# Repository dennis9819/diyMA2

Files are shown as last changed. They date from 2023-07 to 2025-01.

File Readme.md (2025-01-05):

# Modular MIDI-Controller for GrandMA2 Software
*** This project only allows you to controll the grandMA2 Software via a hardware controller. You sitll need to buy a henuine grandMA Interface to unlock the reqired amount of universes. Please also be aware, that this is just a side-project of mine and is not designed for production use. Use the real stuff for that.***

The diyMA is an open source MIDI controller, strongly mimicking the onPC command and fader wing layout. It communicates with the onPC Software via MIDI. This limits the resolution of the faders to 7-Bit (0-127). In my case this is still enough.
I've designed three modules to construct your own modular controller

## The Modules
### Module I : Fader-Module
The fader module contains:
* 5 Executor-Faders (+3 Buttons each)
* 5 Button Executor
* Controller-Header (to connect to Controller-Module)
* 2 PCBs (1x Component-PCB, 1x Panel-PCB)

### Module 3 : Controller-Module
The fader module contains:
* MIDI-In (Passed through for daisy chaining)
* MIDI-Out
* Atmega8-16P @ 16MHz
* 1 ICSP Header (programming)
* +5V/+12V Power Supply

### Module 3 : Fader-Module
The fader module contains:
* 1 Master-Fader
* 69 Buttons
* MIDI-In (Passed through for daisy chaining)
* MIDI-Out
* +5V/+12V Power Supply
* Atmega8-16P @ 16MHz
* 1 Expansion Header (e.g.: more Executors)
* 1 ICSP Header (programming)
* 2 PCBs (1x Component-PCB, 1x Panel-PCB)

## Special-Parts
* https://de.aliexpress.com/item/1005003752250659.html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
* https://de.aliexpress.com/item/1005003201365793.html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
* https://de.aliexpress.com/item/32913352658.html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

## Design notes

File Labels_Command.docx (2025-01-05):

Pause

Go -

Go +

Please

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
Shift

114

14

115

15

5

Group

Preset

Go-

Top

Thru

Fixture

Channel

Exec

Cue

Sequ

Macro

Page

Goto

Effect

View

Pause

Go+

>>>

Learn

<<<

Temp

On

Off

Select

Fix

At

If

Esc

Time

Oops

Bt Pg-

Copy

Freeze

Prev

Edit

Update

Clear

Store

Set

Next

Move

Full

Highlt

Solo

Blind

Prvw

Assign

Align

Up

Down

Ch Pg+

Ch Pg-

Fd Pg+

Fd Pg-

Bt Pg+

B.O.

Tools

Setup

Backup

Del

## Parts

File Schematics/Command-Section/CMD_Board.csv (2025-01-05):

Source: | C:\Users\DG\Desktop\diyMA\Schematics\Command-Section\CMD_Board.kicad_sch
Date: | 9/10/2023 5:42:29 PM
Tool: | Eeschema 7.0.5
Generator: | C:\Program Files\KiCad\7.0\bin\scripting\plugins/bom_csv_grouped_by_value.py
Component Count: | 175
Collated Components:
Item | Qty | Reference(s) | Value | LibPart | Footprint | Datasheet | DNP
1 | 3 | C1, C2, C5 | 100nF | Device:C_Small | Capacitor_THT:C_Rect_L7.0mm_W2.0mm_P5.00mm | ~
2 | 2 | C3, C4 | 33pF | Device:C_Small | Capacitor_THT:C_Rect_L7.0mm_W2.0mm_P5.00mm | ~
3 | 2 | C6, C7 | 100uF | Device:C_Polarized | Capacitor_THT:CP_Radial_D8.0mm_P2.50mm | ~
4 | 2 | D1, D18 | 3V6 | Device:D_Zener | Diode_THT:D_DO-35_SOD27_P10.16mm_Horizontal | ~
5 | 69 | D2, D3, D4, D5, D6, D7, D8, D9, D10, D11, D12, D13, D14, D15, D16, D17, D19, D20, D21, D22, D23, D24, D25, D26, D27, D28, D29, D30, D31, D32, D33, D34, D35, D36, D37, D38, D39, D40, D41, D42, D43, D44, D45, D46, D47, D48, D49, D50, D51, D52, D53, D54, D55, D56, D57, D58, D59, D60, D61, D62, D63, D64, D65, D66, D67, D68, D69, D70, D71 | 1N4001 | Diode:1N4001 | Diode_THT:D_DO-41_SOD81_P10.16mm_Horizontal | http://www.vishay.com/docs/88503/1n4001.pdf
6 | 12 | H1, H2, H3, H4, H5, H6, H7, H8, H9, H10, H11, H12 | MountingHole | Mechanical:MountingHole_Pad | MountingHole:MountingHole_3.2mm_M3_DIN965_Pad | ~
7 | 1 | J1 | USB_B | Connector:USB_B | Connector_USB:USB_B_Lumberg_2411_02_Horizontal | ~
8 | 1 | J2 | Conn_02x05_Odd_Even | Connector_Generic:Conn_02x05_Odd_Even | Connector_IDC:IDC-Header_2x05_P2.54mm_Vertical | ~
9 | 1 | J3 | Conn_01x04_Male | Connector:Conn_01x04_Male | Connector_JST:JST_EH_B4B-EH-A_1x04_P2.50mm_Vertical | ~
10 | 2 | J4, J5 | Conn_02x05_Odd_Even | Connector_Generic:Conn_02x05_Odd_Even | Connector_IDC:IDC-Header_2x05_P2.54mm_Latch_Vertical | ~
11 | 1 | JP1 | Jumper_2_Bridged | Jumper:Jumper_2_Bridged | Jumper:SolderJumper-2_P1.3mm_Bridged_Pad1.0x1.5mm | ~
12 | 1 | R1 | 2k2 | Device:R | Resistor_THT:R_Axial_DIN0207_L6.3mm_D2.5mm_P7.62mm_Horizontal | ~
13 | 2 | R2, R3 | 68 | Device:R | Resistor_THT:R_Axial_DIN0207_L6.3mm_D2.5mm_P7.62mm_Horizontal | ~
14 | 1 | R4 | 10k | Device:R | Resistor_THT:R_Axial_DIN0204_L3.6mm_D1.6mm_P2.54mm_Vertical | ~
15 | 1 | RN1 | R_Network08 | Device:R_Network08 | Resistor_THT:R_Array_SIP9 | http://www.vishay.com/docs/31509/csc.pdf
16 | 1 | RV1 | 10K LIN | Device:R_Potentiometer | w_conn_av:RS60N12-LIN10K | ~
17 | 69 | SW1, SW2, SW3, SW4, SW5, SW6, SW7, SW8, SW9, SW10, SW11, SW12, SW13, SW14, SW15, SW16, SW17, SW18, SW19, SW20, SW21, SW22, SW23, SW24, SW25, SW26, SW27, SW28, SW29, SW30, SW31, SW32, SW33, SW34, SW35, SW36, SW37, SW38, SW39, SW40, SW41, SW42, SW43, SW44, SW45, SW46, SW47, SW48, SW49, SW50, SW51, SW52, SW53, SW54, SW55, SW56, SW57, SW58, SW59, SW60, SW61, SW62, SW63, SW64, SW65, SW66, SW67, SW68, SW69 | Switch_SW_DPST | Z8C rev3-cache:Switch_SW_DPST | cherrymx:SW_Cherry_MX_PCB_1.00u
18 | 1 | U1 | 74HC595 | 74xx:74HC595 | Package_DIP:DIP-16_W7.62mm_Socket_LongPads | http://www.ti.com/lit/ds/symlink/sn74hc595.pdf
19 | 1 | U2 | L7805 | Regulator_Linear:L7805 | Package_TO_SOT_THT:TO-220-3_Horizontal_TabDown | http://www.st.com/content/ccc/resource/technical/document/datasheet/41/4f/b3/b0/12/d4/47/88/CD00000444.pdf/files/CD00000444.pdf/jcr:content/translations/en.CD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
20 | 1 | U3 | ATmega8-16P | MCU_Microchip_ATmega:ATmega8-16P | Package_DIP:DIP-28_W7.62mm_LongPads | http://ww1.microchip.com/downloads/en/DeviceDoc/atmel-2486-8-bit-avr-microcontroller-atmega8_l_datasheet.pdf
21 | 1 | Y1 | 16MHz | Device:Crystal | Crystal:Crystal_HC18-U_Vertical | ~

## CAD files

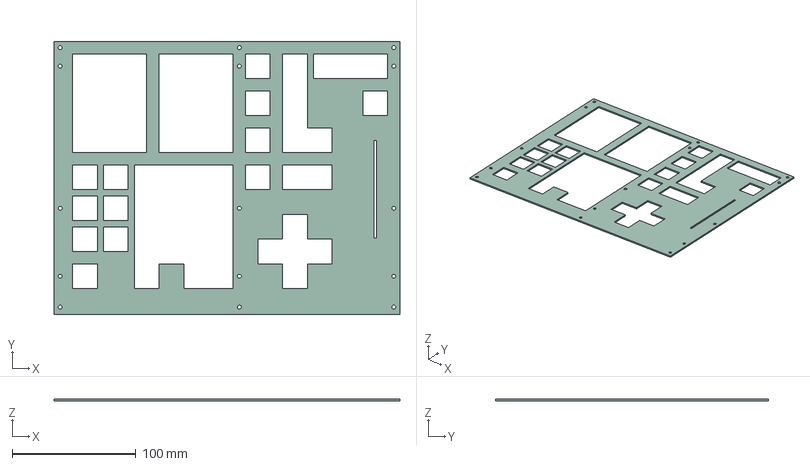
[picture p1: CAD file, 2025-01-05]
Schematics/Command-Section/CMD_Board_cover.step
280.0 x 221.0 x 1.58 mm

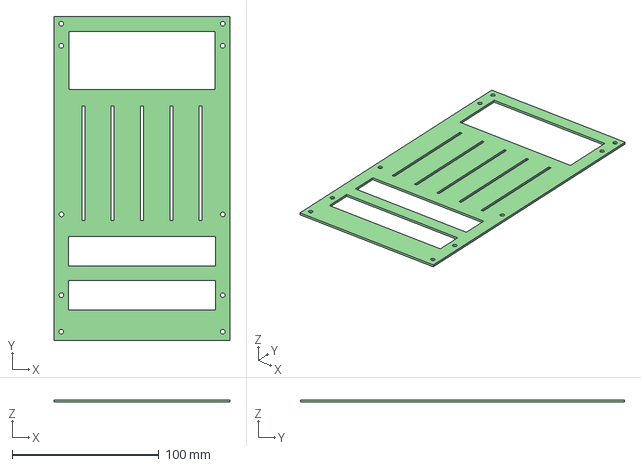
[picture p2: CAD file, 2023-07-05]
Schematics/Fader-Wing V1/Fader_Board_panel.step
120.0 x 221.0 x 1.60 mm

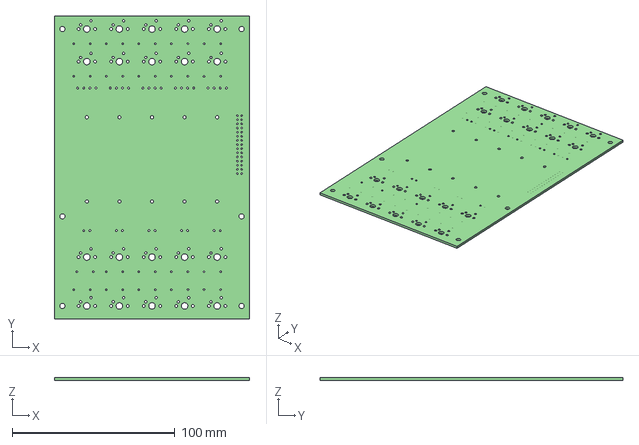
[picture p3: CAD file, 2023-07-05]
Schematics/Fader-Wing V1/Fader_Board.step
120.0 x 186.0 x 1.60 mm

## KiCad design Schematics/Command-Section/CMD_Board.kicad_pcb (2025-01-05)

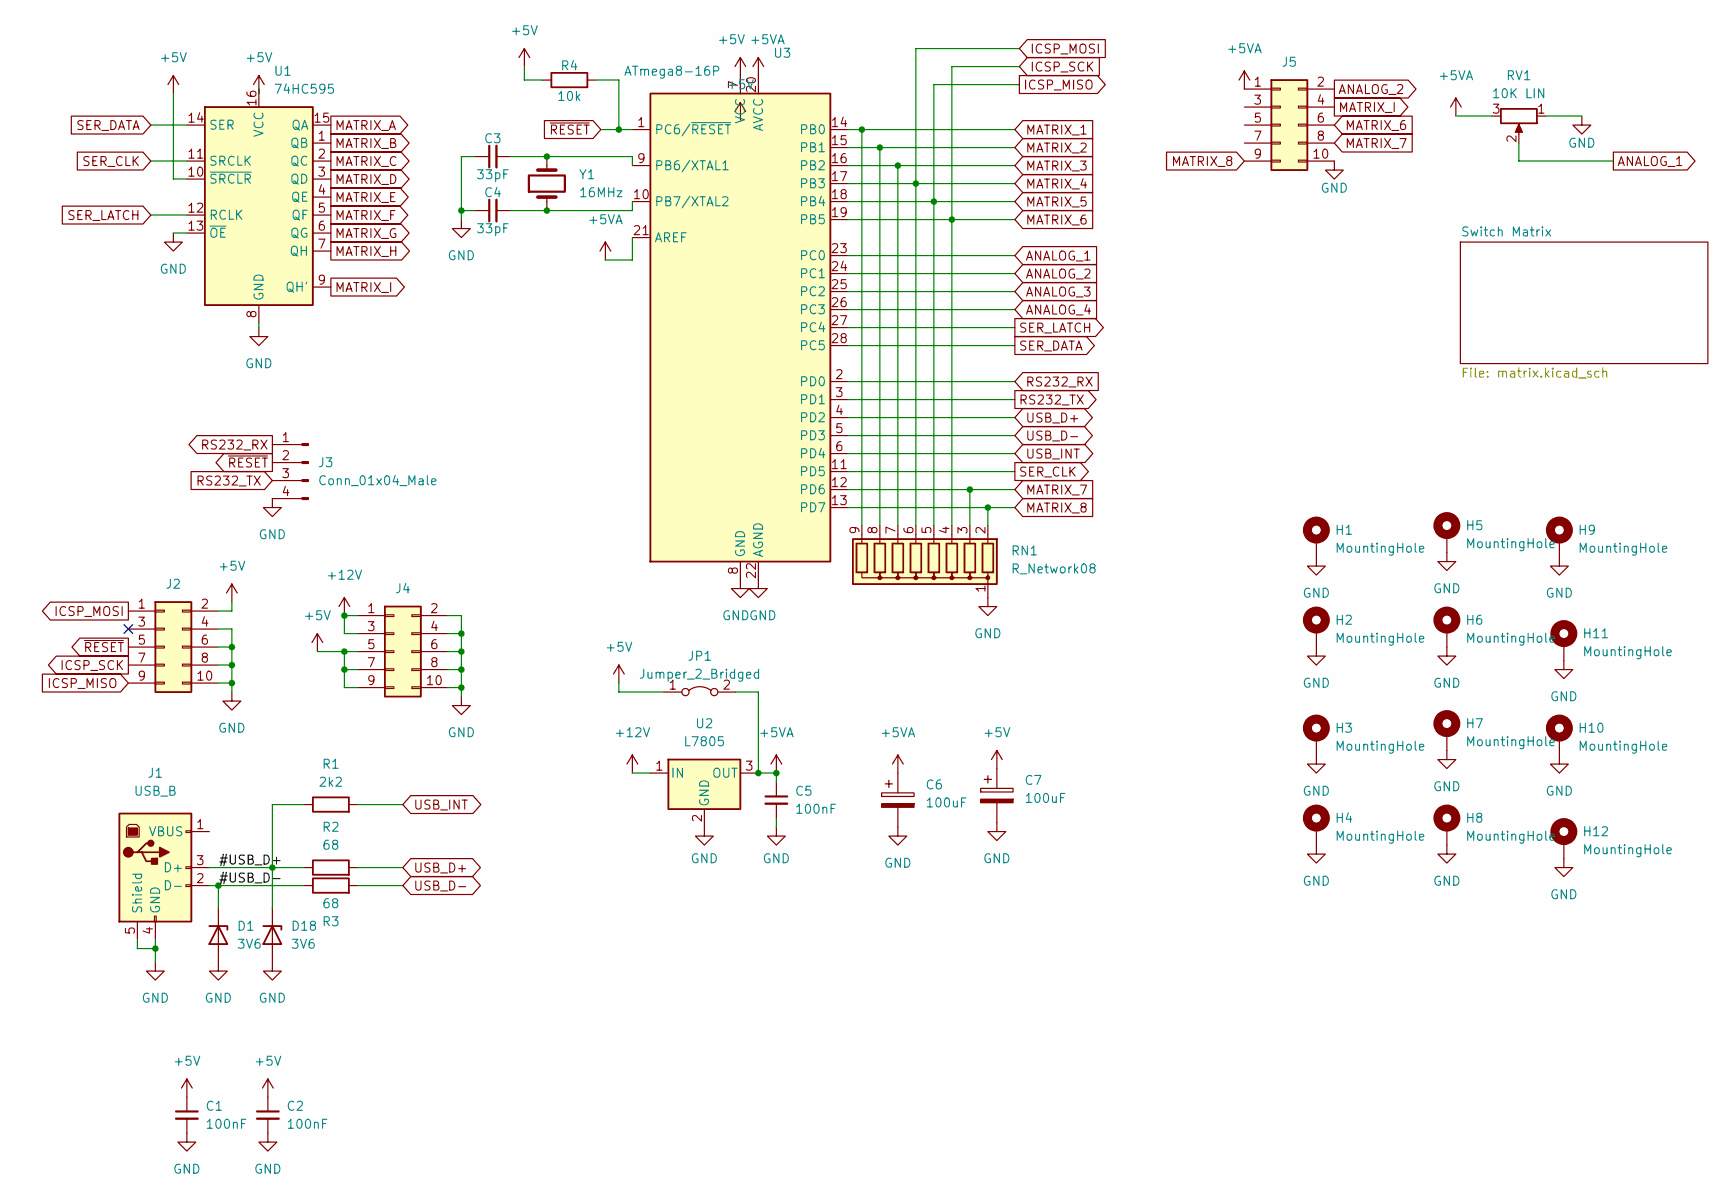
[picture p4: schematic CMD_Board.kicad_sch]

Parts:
C1, C2, C5: 100nF; C_Rect_L7.0mm_W2.0mm_P5.00mm
C3, C4: 33pF; C_Rect_L7.0mm_W2.0mm_P5.00mm
C6, C7: 100uF; CP_Radial_D8.0mm_P2.50mm
D1, D18: 3V6; D_DO-35_SOD27_P10.16mm_Horizontal
H1, H2, H3, H4, H5, H6, H7, H8, H9, H10, H11, H12: MountingHole; MountingHole_3.2mm_M3_DIN965_Pad
J1: USB_B; USB_B_Lumberg_2411_02_Horizontal
J2: Conn_02x05_Odd_Even; IDC-Header_2x05_P2.54mm_Vertical
J3: Conn_01x04_Male; JST_EH_B4B-EH-A_1x04_P2.50mm_Vertical
J4, J5: Conn_02x05_Odd_Even; IDC-Header_2x05_P2.54mm_Latch_Vertical
JP1: Jumper_2_Bridged; SolderJumper-2_P1.3mm_Bridged_Pad1.0x1.5mm
R1: 2k2; R_Axial_DIN0207_L6.3mm_D2.5mm_P7.62mm_Horizontal
R2, R3: 68; R_Axial_DIN0207_L6.3mm_D2.5mm_P7.62mm_Horizontal
R4: 10k; R_Axial_DIN0204_L3.6mm_D1.6mm_P2.54mm_Vertical
RN1: R_Network08; R_Array_SIP9
RV1: 10K LIN; RS60N12-LIN10K
U1: 74HC595; DIP-16_W7.62mm_Socket_LongPads
U2: L7805; TO-220-3_Horizontal_TabDown
U3: ATmega8-16P; DIP-28_W7.62mm_LongPads
Y1: 16MHz; Crystal_HC18-U_Vertical

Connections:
+5V: C1.1, C2.1, C7.1, J2.2, J4.5, J4.7, J4.9, JP1.1 (A), R4.1, U1.10 (~SRCLR), U1.16 (VCC), U3.7 (VCC)
+5VA: C5.1, C6.1, J5.1, JP1.2 (B), RV1.3, U2.3 (OUT), U3.20 (AVCC), U3.21 (AREF)
+12V: J4.1, J4.3, U2.1 (IN)
/#USB_D+: D18.1 (K), J1.3 (D+), R1.1, R2.1
/#USB_D-: D1.1 (K), J1.2 (D-), R3.1
ANALOG_1: RV1.2, U3.23 (PC0)
ANALOG_2: J5.2, U3.24 (PC1)
ANALOG_3: U3.25 (PC2)
ANALOG_4: U3.26 (PC3)
GND: C1.2, C2.2, C3.1, C4.1, C5.2, C6.2, C7.2, D1.2 (A), D18.2 (A), H1.1, H2.1, H3.1, H4.1, H5.1, H6.1, H7.1, H8.1, H9.1, H10.1, H11.1, H12.1, J1.4 (GND), J1.5 (Shield), J2.4, J2.6, J2.8, J2.10, J3.4, J4.2, J4.4, J4.6, J4.8, J4.10, J5.10, RN1.1 (common), RV1.1, U1.8 (GND), U1.13 (~OE), U2.2 (GND), U3.8 (GND), U3.22 (AGND); also elsewhere on the board
ICSP_MISO: J2.9, RN1.5 (R4), U3.18 (PB4); also elsewhere on the board
ICSP_MOSI: J2.1, RN1.6 (R5), U3.17 (PB3); also elsewhere on the board
ICSP_SCK: J2.7, J5.6, RN1.4 (R3), U3.19 (PB5); also elsewhere on the board
MATRIX_1: RN1.9 (R8), U3.14 (PB0); also elsewhere on the board
MATRIX_2: RN1.8 (R7), U3.15 (PB1); also elsewhere on the board
MATRIX_3: RN1.7 (R6), U3.16 (PB2); also elsewhere on the board
MATRIX_7: J5.8, RN1.3 (R2), U3.12 (PD6); also elsewhere on the board
MATRIX_8: J5.9, RN1.2 (R1), U3.13 (PD7); also elsewhere on the board
MATRIX_A: U1.15 (QA); also elsewhere on the board
MATRIX_B: U1.1 (QB); also elsewhere on the board
MATRIX_C: U1.2 (QC); also elsewhere on the board
MATRIX_D: U1.3 (QD); also elsewhere on the board
MATRIX_E: U1.4 (QE); also elsewhere on the board
MATRIX_F: U1.5 (QF); also elsewhere on the board
MATRIX_G: U1.6 (QG); also elsewhere on the board
MATRIX_H: U1.7 (QH); also elsewhere on the board
MATRIX_I: J5.4, U1.9 (QH'); also elsewhere on the board
unnamed: C3.2, U3.9 (PB6/XTAL1), Y1.2
unnamed: C4.2, U3.10 (PB7/XTAL2), Y1.1
RS232_RX: J3.1, U3.2 (PD0)
RS232_TX: J3.3, U3.3 (PD1)
SER_CLK: U1.11 (SRCLK), U3.11 (PD5)
SER_DATA: U1.14 (SER), U3.28 (PC5)
SER_LATCH: U1.12 (RCLK), U3.27 (PC4)
USB_D+: R2.2, U3.4 (PD2)
USB_D-: R3.2, U3.5 (PD3)
USB_INT: R1.2, U3.6 (PD4)
~RESET: J2.5, J3.2, R4.2, U3.1 (PC6/~RESET)

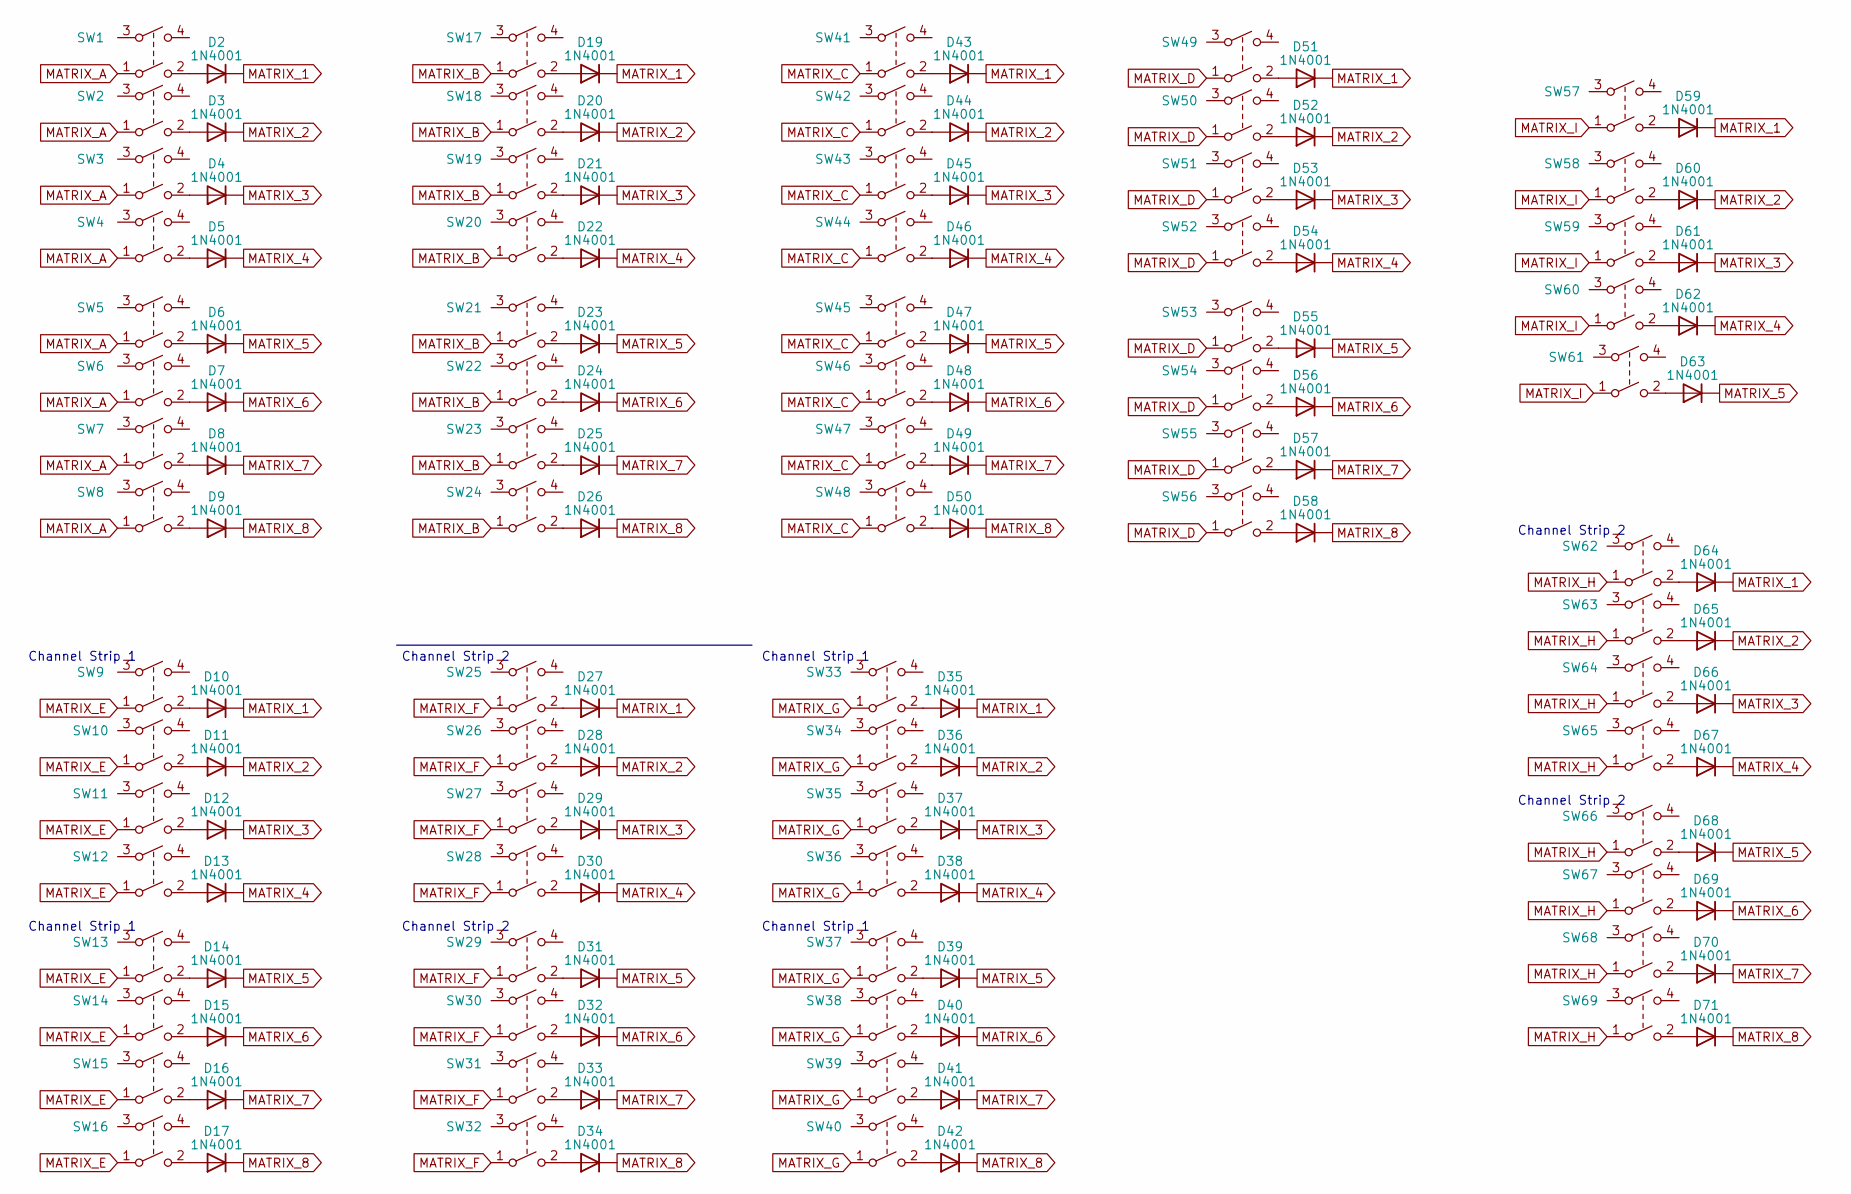
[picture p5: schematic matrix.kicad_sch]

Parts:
D2, D3, D4, D5, D6, D7, D8, D9, D10, D11, D12, D13, D14, D15, D16, D17, D19, D20, D21, D22, D23, D24, D25, D26, D27, D28, D29, D30, D31, D32, D33, D34, D35, D36, D37, D38, D39, D40, D41, D42, D43, D44, D45, D46, D47, D48, D49, D50, D51, D52, D53, D54, D55, D56, D57, D58, D59, D60, D61, D62, D63, D64, D65, D66, D67, D68, D69, D70, D71: 1N4001; D_DO-41_SOD81_P10.16mm_Horizontal
SW1, SW2, SW3, SW4, SW5, SW6, SW7, SW8, SW9, SW10, SW11, SW12, SW13, SW14, SW15, SW16, SW17, SW18, SW19, SW20, SW21, SW22, SW23, SW24, SW25, SW26, SW27, SW28, SW29, SW30, SW31, SW32, SW33, SW34, SW35, SW36, SW37, SW38, SW39, SW40, SW41, SW42, SW43, SW44, SW45, SW46, SW47, SW48, SW49, SW50, SW51, SW52, SW53, SW54, SW55, SW56, SW57, SW58, SW59, SW60, SW61, SW62, SW63, SW64, SW65, SW66, SW67, SW68, SW69: Switch_SW_DPST; SW_Cherry_MX_PCB_1.00u

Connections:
ICSP_MISO: D6.1 (K), D14.1 (K), D23.1 (K), D31.1 (K), D39.1 (K), D47.1 (K), D55.1 (K), D63.1 (K), D68.1 (K); also elsewhere on the board
ICSP_MOSI: D5.1 (K), D13.1 (K), D22.1 (K), D30.1 (K), D38.1 (K), D46.1 (K), D54.1 (K), D62.1 (K), D67.1 (K); also elsewhere on the board
ICSP_SCK: D7.1 (K), D15.1 (K), D24.1 (K), D32.1 (K), D40.1 (K), D48.1 (K), D56.1 (K), D69.1 (K); also elsewhere on the board
MATRIX_1: D2.1 (K), D10.1 (K), D19.1 (K), D27.1 (K), D35.1 (K), D43.1 (K), D51.1 (K), D59.1 (K), D64.1 (K); also elsewhere on the board
MATRIX_2: D3.1 (K), D11.1 (K), D20.1 (K), D28.1 (K), D36.1 (K), D44.1 (K), D52.1 (K), D60.1 (K), D65.1 (K); also elsewhere on the board
MATRIX_3: D4.1 (K), D12.1 (K), D21.1 (K), D29.1 (K), D37.1 (K), D45.1 (K), D53.1 (K), D61.1 (K), D66.1 (K); also elsewhere on the board
MATRIX_7: D8.1 (K), D16.1 (K), D25.1 (K), D33.1 (K), D41.1 (K), D49.1 (K), D57.1 (K), D70.1 (K); also elsewhere on the board
MATRIX_8: D9.1 (K), D17.1 (K), D26.1 (K), D34.1 (K), D42.1 (K), D50.1 (K), D58.1 (K), D71.1 (K); also elsewhere on the board
MATRIX_A: SW1.1, SW2.1, SW3.1, SW4.1, SW5.1, SW6.1, SW7.1, SW8.1; also elsewhere on the board
MATRIX_B: SW17.1, SW18.1, SW19.1, SW20.1, SW21.1, SW22.1, SW23.1, SW24.1; also elsewhere on the board
MATRIX_C: SW41.1, SW42.1, SW43.1, SW44.1, SW45.1, SW46.1, SW47.1, SW48.1; also elsewhere on the board
MATRIX_D: SW49.1, SW50.1, SW51.1, SW52.1, SW53.1, SW54.1, SW55.1, SW56.1; also elsewhere on the board
MATRIX_E: SW9.1, SW10.1, SW11.1, SW12.1, SW13.1, SW14.1, SW15.1, SW16.1; also elsewhere on the board
MATRIX_F: SW25.1, SW26.1, SW27.1, SW28.1, SW29.1, SW30.1, SW31.1, SW32.1; also elsewhere on the board
MATRIX_G: SW33.1, SW34.1, SW35.1, SW36.1, SW37.1, SW38.1, SW39.1, SW40.1; also elsewhere on the board
MATRIX_H: SW62.1, SW63.1, SW64.1, SW65.1, SW66.1, SW67.1, SW68.1, SW69.1; also elsewhere on the board
MATRIX_I: SW57.1, SW58.1, SW59.1, SW60.1, SW61.1; also elsewhere on the board
unnamed: D2.2 (A), SW1.2
unnamed: D3.2 (A), SW2.2
unnamed: D4.2 (A), SW3.2
unnamed: D5.2 (A), SW4.2
unnamed: D6.2 (A), SW5.2
unnamed: D7.2 (A), SW6.2
unnamed: D8.2 (A), SW7.2
unnamed: D9.2 (A), SW8.2
unnamed: D10.2 (A), SW9.2
unnamed: D11.2 (A), SW10.2
unnamed: D12.2 (A), SW11.2
unnamed: D13.2 (A), SW12.2
unnamed: D14.2 (A), SW13.2
unnamed: D15.2 (A), SW14.2
unnamed: D16.2 (A), SW15.2
unnamed: D17.2 (A), SW16.2
unnamed: D19.2 (A), SW17.2
unnamed: D20.2 (A), SW18.2
unnamed: D21.2 (A), SW19.2
unnamed: D22.2 (A), SW20.2
unnamed: D23.2 (A), SW21.2
unnamed: D24.2 (A), SW22.2
unnamed: D25.2 (A), SW23.2
unnamed: D26.2 (A), SW24.2
unnamed: D27.2 (A), SW25.2
unnamed: D28.2 (A), SW26.2
unnamed: D29.2 (A), SW27.2
unnamed: D30.2 (A), SW28.2
unnamed: D31.2 (A), SW29.2
unnamed: D32.2 (A), SW30.2
unnamed: D33.2 (A), SW31.2
unnamed: D34.2 (A), SW32.2
unnamed: D35.2 (A), SW33.2
unnamed: D36.2 (A), SW34.2
unnamed: D37.2 (A), SW35.2
unnamed: D38.2 (A), SW36.2
unnamed: D39.2 (A), SW37.2
unnamed: D40.2 (A), SW38.2
unnamed: D41.2 (A), SW39.2
unnamed: D42.2 (A), SW40.2
unnamed: D43.2 (A), SW41.2
unnamed: D44.2 (A), SW42.2
unnamed: D45.2 (A), SW43.2
unnamed: D46.2 (A), SW44.2
unnamed: D47.2 (A), SW45.2
unnamed: D48.2 (A), SW46.2
unnamed: D49.2 (A), SW47.2
unnamed: D50.2 (A), SW48.2
unnamed: D51.2 (A), SW49.2
unnamed: D52.2 (A), SW50.2
unnamed: D53.2 (A), SW51.2
unnamed: D54.2 (A), SW52.2
unnamed: D55.2 (A), SW53.2
unnamed: D56.2 (A), SW54.2
unnamed: D57.2 (A), SW55.2
unnamed: D58.2 (A), SW56.2
unnamed: D59.2 (A), SW57.2
unnamed: D60.2 (A), SW58.2
unnamed: D61.2 (A), SW59.2
unnamed: D62.2 (A), SW60.2
unnamed: D63.2 (A), SW61.2
unnamed: D64.2 (A), SW62.2
unnamed: D65.2 (A), SW63.2
unnamed: D66.2 (A), SW64.2
unnamed: D67.2 (A), SW65.2
unnamed: D68.2 (A), SW66.2
unnamed: D69.2 (A), SW67.2
unnamed: D70.2 (A), SW68.2
unnamed: D71.2 (A), SW69.2

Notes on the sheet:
Channel Strip 2
Channel Strip 1

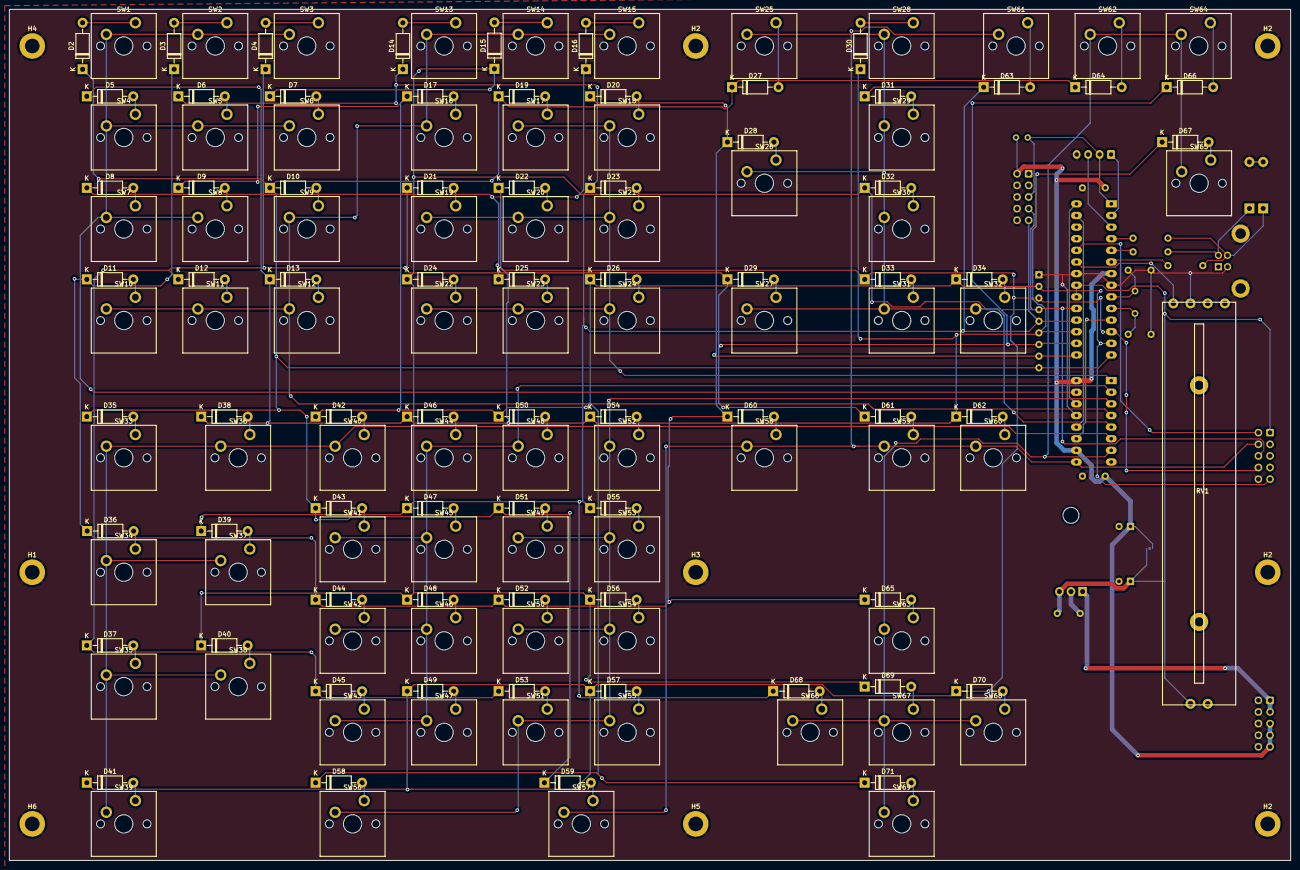
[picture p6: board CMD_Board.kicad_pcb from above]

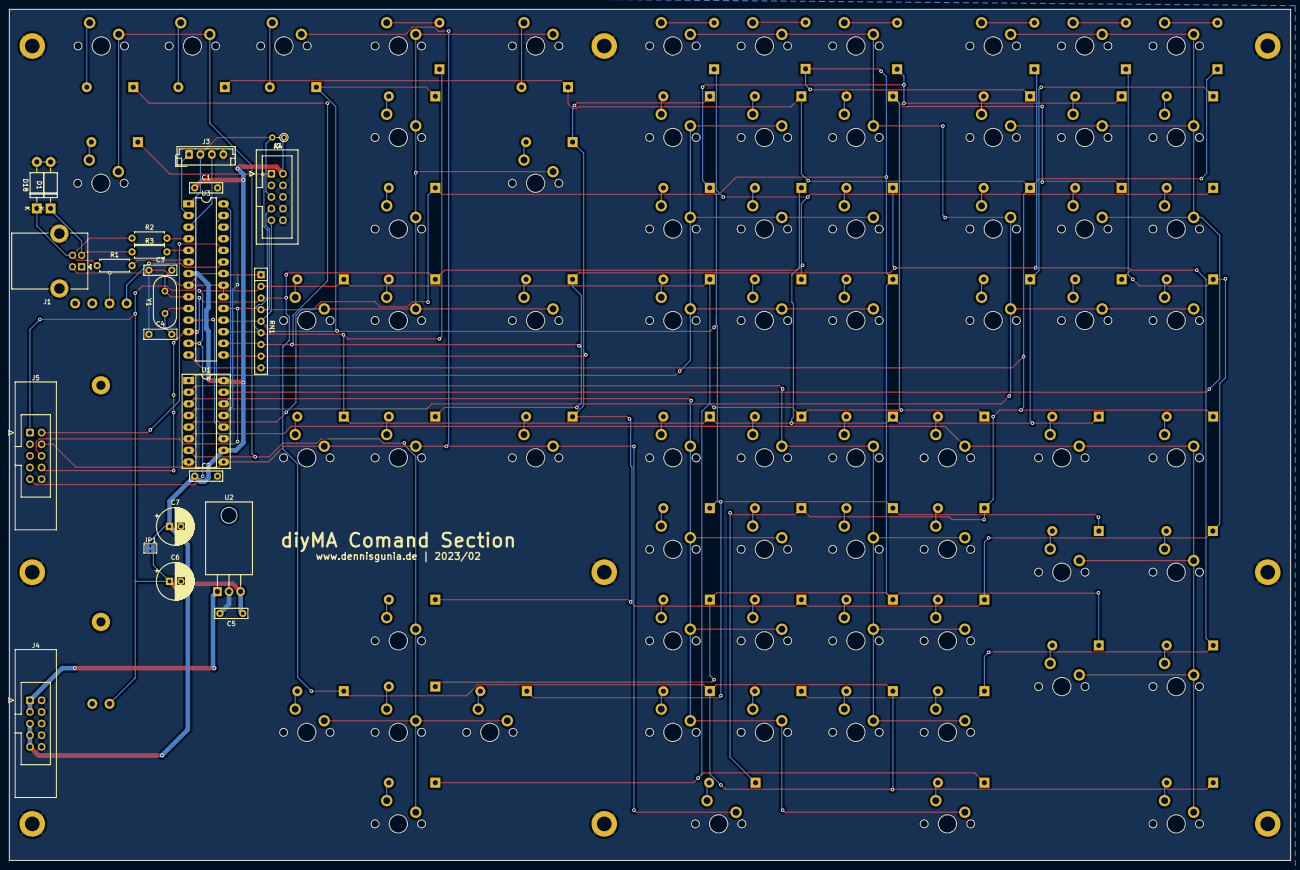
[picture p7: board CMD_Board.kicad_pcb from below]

Board: 2 copper layers, 280.0 x 186.0 mm, 172 parts (24 on the bottom side), 105 nets.

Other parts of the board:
H2#2, H2#3, H2#4: MountingHole; MountingHole_3.2mm_M3_DIN965_Pad

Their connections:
GND: H2#2.1, H2#3.1, H2#4.1; also elsewhere on the board

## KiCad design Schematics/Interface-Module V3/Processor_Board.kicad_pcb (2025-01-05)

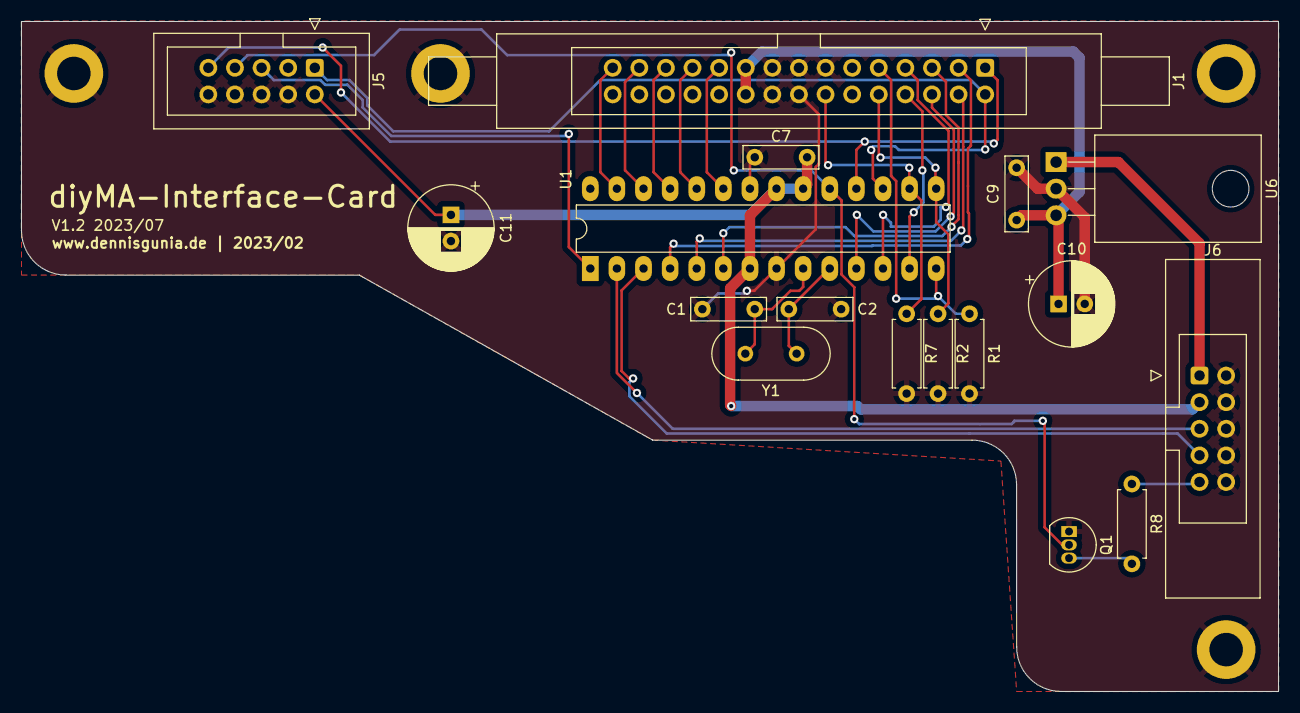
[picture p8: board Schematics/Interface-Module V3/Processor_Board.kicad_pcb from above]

Board: 2 copper layers, 120.0 x 64.0 mm, 21 parts (0 on the bottom side), 28 nets.

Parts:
C1, C2: 33pF; C_Rect_L7.0mm_W2.0mm_P5.00mm
C7, C9: 100nF; C_Rect_L7.0mm_W2.0mm_P5.00mm
C10, C11: 100uF; CP_Radial_D8.0mm_P2.50mm
H4, H6, H6#2, H8: MountingHole; MountingHole_3.2mm_M3_DIN965_Pad
J1: Conn_02x16_Odd_Even; IDC-Header_2x15_P2.54mm_Latch6.5mm_Vertical
J5: Conn_02x05_Odd_Even; IDC-Header_2x05_P2.54mm_Vertical
J6: Conn_02x05_Odd_Even; IDC-Header_2x05_P2.54mm_Latch_Vertical
Q1: 2N3904; TO-92_Inline
R1, R2, R7: 10k; R_Axial_DIN0207_L6.3mm_D2.5mm_P7.62mm_Horizontal
R8: 100; R_Axial_DIN0207_L6.3mm_D2.5mm_P7.62mm_Horizontal
U1: ATmega8-16P; DIP-28_W7.62mm_LongPads
U6: L7805; TO-220-3_Horizontal_TabDown
Y1: 16MHz; Crystal_HC18-U_Vertical

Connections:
+5V: C7.1, C11.1, J5.2, J6.3, U1.7 (VCC), U1.20 (AVCC), U1.21 (AREF)
+5VA: C9.1, C10.1, J1.19, J1.20, U6.3 (OUT)
+12V: J6.1, U6.1 (IN)
ANALOG_11: J1.21, U1.23 (PC0)
ANALOG_12: J1.23, U1.24 (PC1)
ANALOG_13: J1.25, U1.25 (PC2)
ANALOG_14: J1.27, U1.26 (PC3)
ANALOG_15: J1.29, U1.27 (PC4)
GND: C1.1, C2.1, C7.2, C9.2, C10.2, C11.2, H4.1, H6.1, H6#2.1, H8.1, J1.13, J1.15, J1.16, J1.17, J1.18, J1.22, J1.24, J1.26, J1.28, J1.30, J5.4, J5.6, J5.8, J5.10, J6.2, J6.4, J6.6, J6.8, J6.10, Q1.1 (E), R1.2, R2.2, R7.2, U1.8 (GND), U1.22 (AGND), U6.2 (GND)
ICSP2_MISO: J1.1, J5.9, U1.18 (PB4)
ICSP2_MOSI: J1.2, J5.1, U1.17 (PB3)
ICSP2_SCK: J5.7, Q1.2 (B), U1.19 (PB5)
MATRIX_3: J1.3, U1.4 (PD2)
MATRIX_4: J1.4, U1.5 (PD3)
MATRIX_5: J1.5, U1.6 (PD4)
MATRIX_6: J1.6, U1.11 (PD5)
MATRIX_7: J1.7, U1.12 (PD6)
MATRIX_8: J1.8, U1.13 (PD7)
MATRIX_A: J1.9, R1.1, U1.14 (PB0)
MATRIX_B: J1.10, R2.1, U1.15 (PB1)
MATRIX_C: J1.14, R7.1, U1.16 (PB2)
unnamed: Q1.3 (C), R8.2
unnamed: C1.2, U1.9 (PB6/XTAL1), Y1.2
unnamed: C2.2, U1.10 (PB7/XTAL2), Y1.1
RX: J6.7, U1.3 (PD1)
TX: J6.5, U1.2 (PD0)
\EVNT: J6.9, R8.1
~RESET: J5.5, U1.1 (PC6/~RESET)

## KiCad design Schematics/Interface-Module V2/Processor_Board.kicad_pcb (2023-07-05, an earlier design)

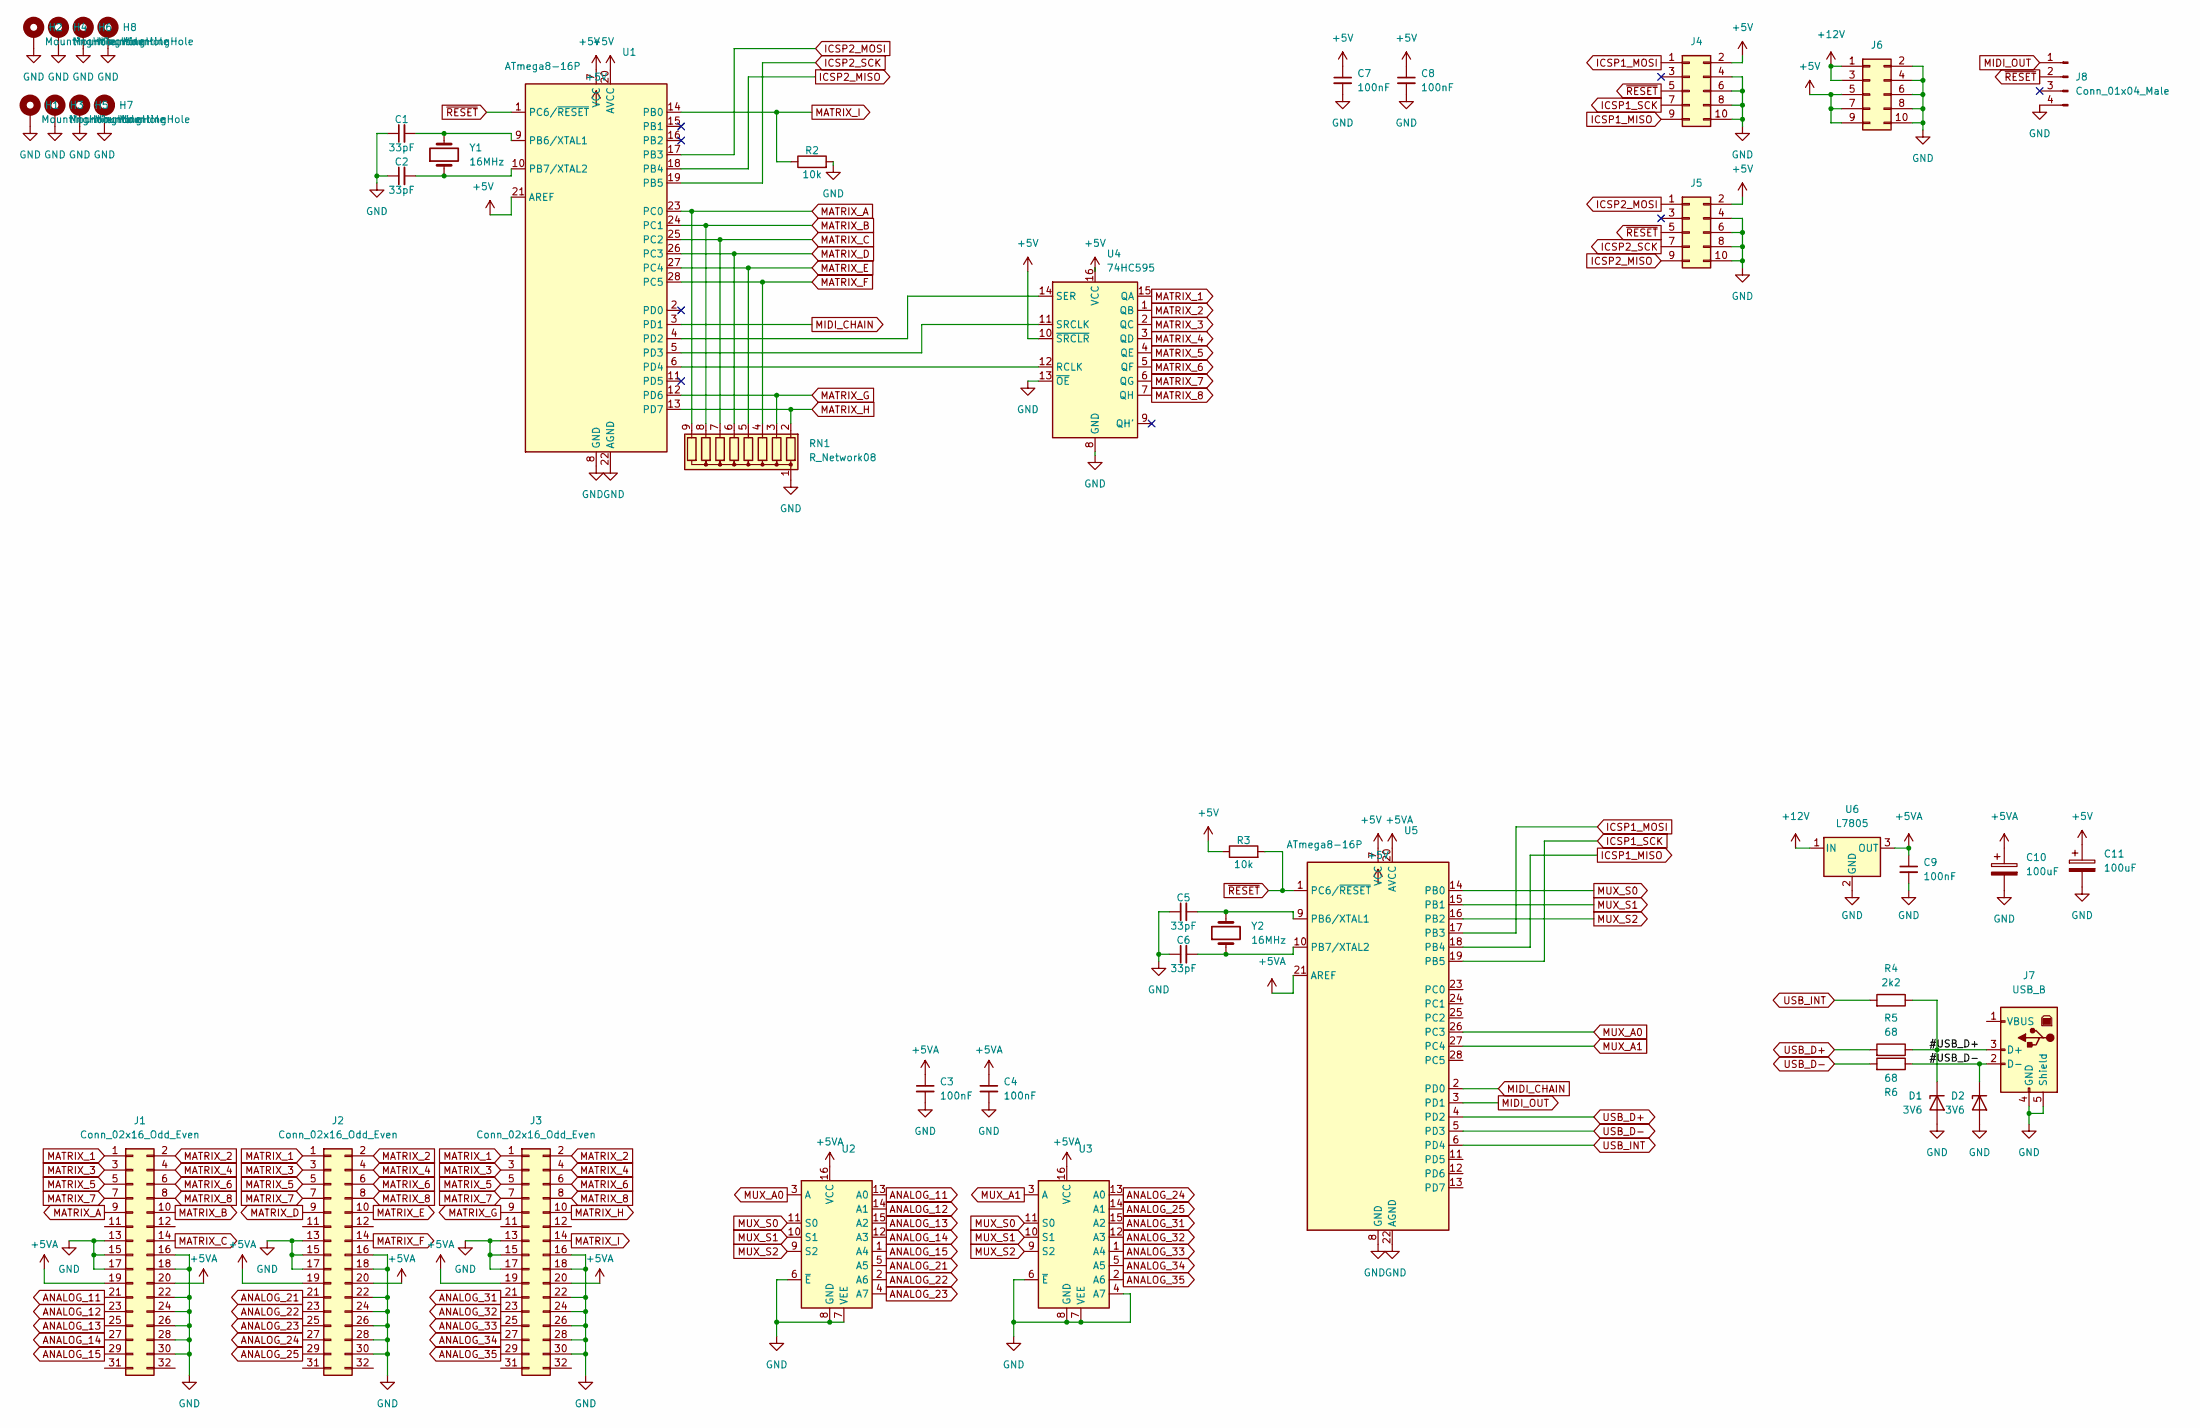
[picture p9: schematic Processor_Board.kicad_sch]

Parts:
C1, C2, C5, C6: 33pF; C_Rect_L7.0mm_W2.0mm_P5.00mm
C3, C4, C7, C8, C9: 100nF; C_Rect_L7.0mm_W2.0mm_P5.00mm
C10, C11: 100uF; CP_Radial_D8.0mm_P2.50mm
D1, D2: 3V6; D_DO-35_SOD27_P10.16mm_Horizontal
H1, H2, H3, H4, H5, H6, H7, H8: MountingHole; MountingHole_3.2mm_M3_DIN965_Pad
J1, J2, J3: Conn_02x16_Odd_Even; IDC-Header_2x15_P2.54mm_Latch6.5mm_Vertical
J4, J5: Conn_02x05_Odd_Even; IDC-Header_2x05_P2.54mm_Vertical
J6: Conn_02x05_Odd_Even; IDC-Header_2x05_P2.54mm_Latch_Vertical
J7: USB_B; USB_B_Lumberg_2411_02_Horizontal
J8: Conn_01x04_Male; JST_EH_B4B-EH-A_1x04_P2.50mm_Vertical
R2, R3: 10k; R_Axial_DIN0204_L3.6mm_D1.6mm_P2.54mm_Vertical
R4: 2k2; R_Axial_DIN0207_L6.3mm_D2.5mm_P7.62mm_Horizontal
R5, R6: 68; R_Axial_DIN0207_L6.3mm_D2.5mm_P7.62mm_Horizontal
RN1: R_Network08; R_Array_SIP9
U1, U5: ATmega8-16P; DIP-28_W7.62mm_LongPads
U2, U3: (no value)
U4: 74HC595; DIP-16_W10.16mm_LongPads
U6: L7805; TO-220-3_Horizontal_TabDown
Y1, Y2: 16MHz; Crystal_HC18-U_Vertical

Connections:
+5V: C7.1, C8.1, C11.1, J4.2, J5.2, J6.5, J6.7, J6.9, R3.1, U1.7 (VCC), U1.20 (AVCC), U1.21 (AREF), U4.10 (~SRCLR), U4.16 (VCC), U5.7 (VCC)
+5VA: C3.1, C4.1, C9.1, C10.1, J1.19, J1.20, J2.19, J2.20, J3.19, J3.20, U2.16 (VCC), U3.16 (VCC), U5.20 (AVCC), U5.21 (AREF), U6.3 (OUT)
+12V: J6.1, J6.3, U6.1 (IN)
/#USB_D+: D1.1 (K), J7.3 (D+), R4.1, R5.1
/#USB_D-: D2.1 (K), J7.2 (D-), R6.1
ANALOG_11: J1.21, U2.13 (A0)
ANALOG_12: J1.23, U2.14 (A1)
ANALOG_13: J1.25, U2.15 (A2)
ANALOG_14: J1.27, U2.12 (A3)
ANALOG_15: J1.29, U2.1 (A4)
ANALOG_21: J2.21, U2.5 (A5)
ANALOG_22: J2.23, U2.2 (A6)
ANALOG_23: J2.25, U2.4 (A7)
ANALOG_24: J2.27, U3.13 (A0)
ANALOG_25: J2.29, U3.14 (A1)
ANALOG_31: J3.21, U3.15 (A2)
ANALOG_32: J3.23, U3.12 (A3)
ANALOG_33: J3.25, U3.1 (A4)
ANALOG_34: J3.27, U3.5 (A5)
ANALOG_35: J3.29, U3.2 (A6)
GND: C1.1, C2.1, C3.2, C4.2, C5.1, C6.1, C7.2, C8.2, C9.2, C10.2, C11.2, D1.2 (A), D2.2 (A), H1.1, H2.1, H3.1, H4.1, H5.1, H6.1, H7.1, H8.1, J1.13, J1.15, J1.16, J1.17, J1.18, J1.22, J1.24, J1.26, J1.28, J1.30, J2.13, J2.15, J2.16, J2.17, J2.18, J2.22, J2.24, J2.26, J2.28, J2.30, J3.13, J3.15, J3.16, J3.17, J3.18, J3.22, J3.24, J3.26, J3.28, J3.30, J4.4, J4.6, J4.8, J4.10, J5.4, J5.6, J5.8, J5.10, J6.2, J6.4, J6.6, J6.8, J6.10, J7.4 (GND), J7.5 (Shield), J8.4, R2.2, RN1.1 (common), U1.8 (GND), U1.22 (AGND), U2.6 (~E), U2.7 (VEE), U2.8 (GND), U3.4 (A7), U3.6 (~E), U3.7 (VEE), U3.8 (GND), U4.8 (GND), U4.13 (~OE), U5.8 (GND), U5.22 (AGND), U6.2 (GND)
ICSP1_MISO: J4.9, U5.18 (PB4)
ICSP1_MOSI: J4.1, U5.17 (PB3)
ICSP1_SCK: J4.7, U5.19 (PB5)
ICSP2_MISO: J5.9, U1.18 (PB4)
ICSP2_MOSI: J5.1, U1.17 (PB3)
ICSP2_SCK: J5.7, U1.19 (PB5)
MATRIX_1: J1.1, J2.1, J3.1, U4.15 (QA)
MATRIX_2: J1.2, J2.2, J3.2, U4.1 (QB)
MATRIX_3: J1.3, J2.3, J3.3, U4.2 (QC)
MATRIX_4: J1.4, J2.4, J3.4, U4.3 (QD)
MATRIX_5: J1.5, J2.5, J3.5, U4.4 (QE)
MATRIX_6: J1.6, J2.6, J3.6, U4.5 (QF)
MATRIX_7: J1.7, J2.7, J3.7, U4.6 (QG)
MATRIX_8: J1.8, J2.8, J3.8, U4.7 (QH)
MATRIX_A: J1.9, RN1.9 (R8), U1.23 (PC0)
MATRIX_B: J1.10, RN1.8 (R7), U1.24 (PC1)
MATRIX_C: J1.14, RN1.7 (R6), U1.25 (PC2)
MATRIX_D: J2.9, RN1.6 (R5), U1.26 (PC3)
MATRIX_E: J2.10, RN1.5 (R4), U1.27 (PC4)
MATRIX_F: J2.14, RN1.4 (R3), U1.28 (PC5)
MATRIX_G: J3.9, RN1.3 (R2), U1.12 (PD6)
MATRIX_H: J3.10, RN1.2 (R1), U1.13 (PD7)
MATRIX_I: J3.14, R2.1, U1.14 (PB0)
MIDI_CHAIN: U1.3 (PD1), U5.2 (PD0)
MIDI_OUT: J8.1, U5.3 (PD1)
MUX_A0: U2.3 (A), U5.26 (PC3)
MUX_A1: U3.3 (A), U5.27 (PC4)
MUX_S0: U2.11 (S0), U3.11 (S0), U5.14 (PB0)
MUX_S1: U2.10 (S1), U3.10 (S1), U5.15 (PB1)
MUX_S2: U2.9 (S2), U3.9 (S2), U5.16 (PB2)
unnamed: C1.2, U1.9 (PB6/XTAL1), Y1.2
unnamed: C2.2, U1.10 (PB7/XTAL2), Y1.1
unnamed: C5.2, U5.9 (PB6/XTAL1), Y2.2
unnamed: C6.2, U5.10 (PB7/XTAL2), Y2.1
unnamed: U1.5 (PD3), U4.11 (SRCLK)
unnamed: U1.6 (PD4), U4.12 (RCLK)
unnamed: U1.4 (PD2), U4.14 (SER)
USB_D+: R5.2, U5.4 (PD2)
USB_D-: R6.2, U5.5 (PD3)
USB_INT: R4.2, U5.6 (PD4)
~RESET: J4.5, J5.5, J8.2, R3.2, U1.1 (PC6/~RESET), U5.1 (PC6/~RESET)

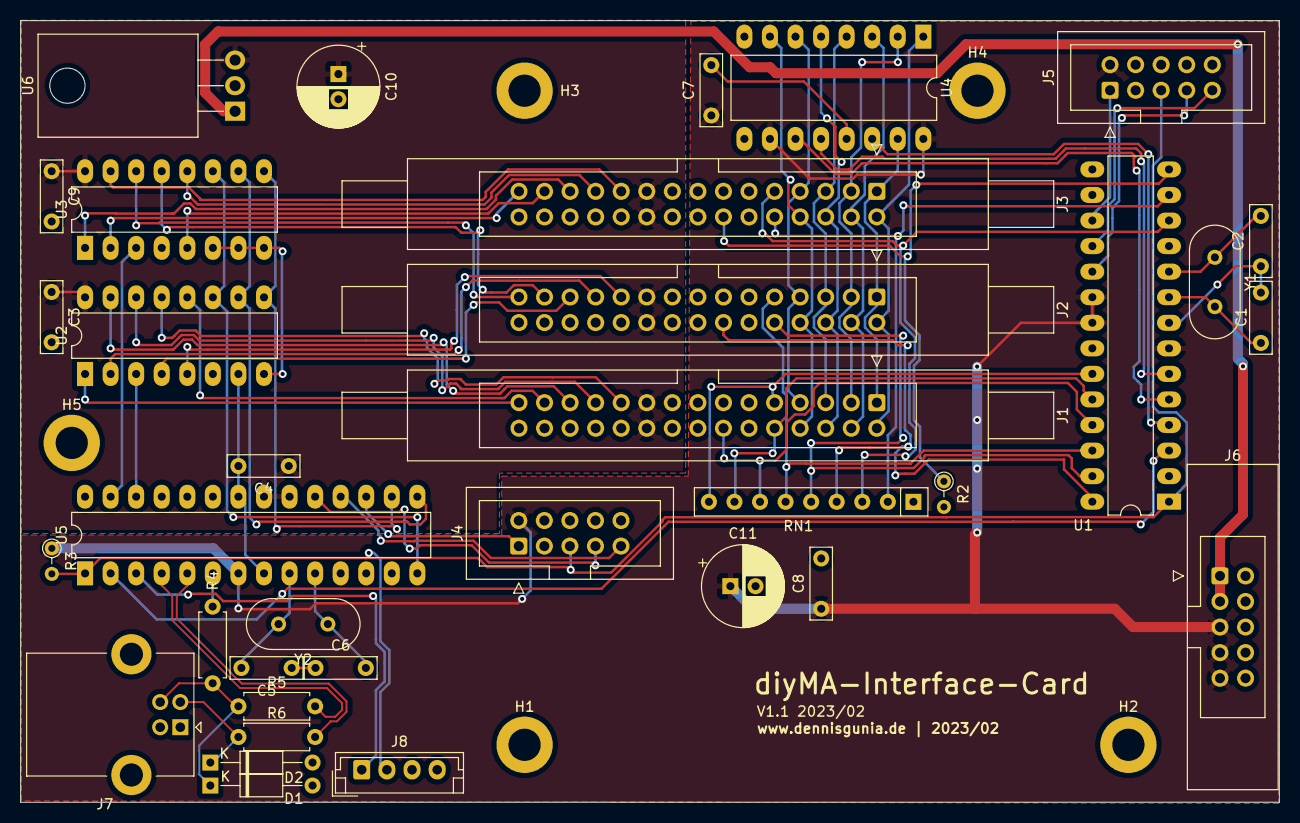
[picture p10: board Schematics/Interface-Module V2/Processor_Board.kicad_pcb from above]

Board: 2 copper layers, 125.1 x 77.7 mm, 40 parts (0 on the bottom side), 62 nets.

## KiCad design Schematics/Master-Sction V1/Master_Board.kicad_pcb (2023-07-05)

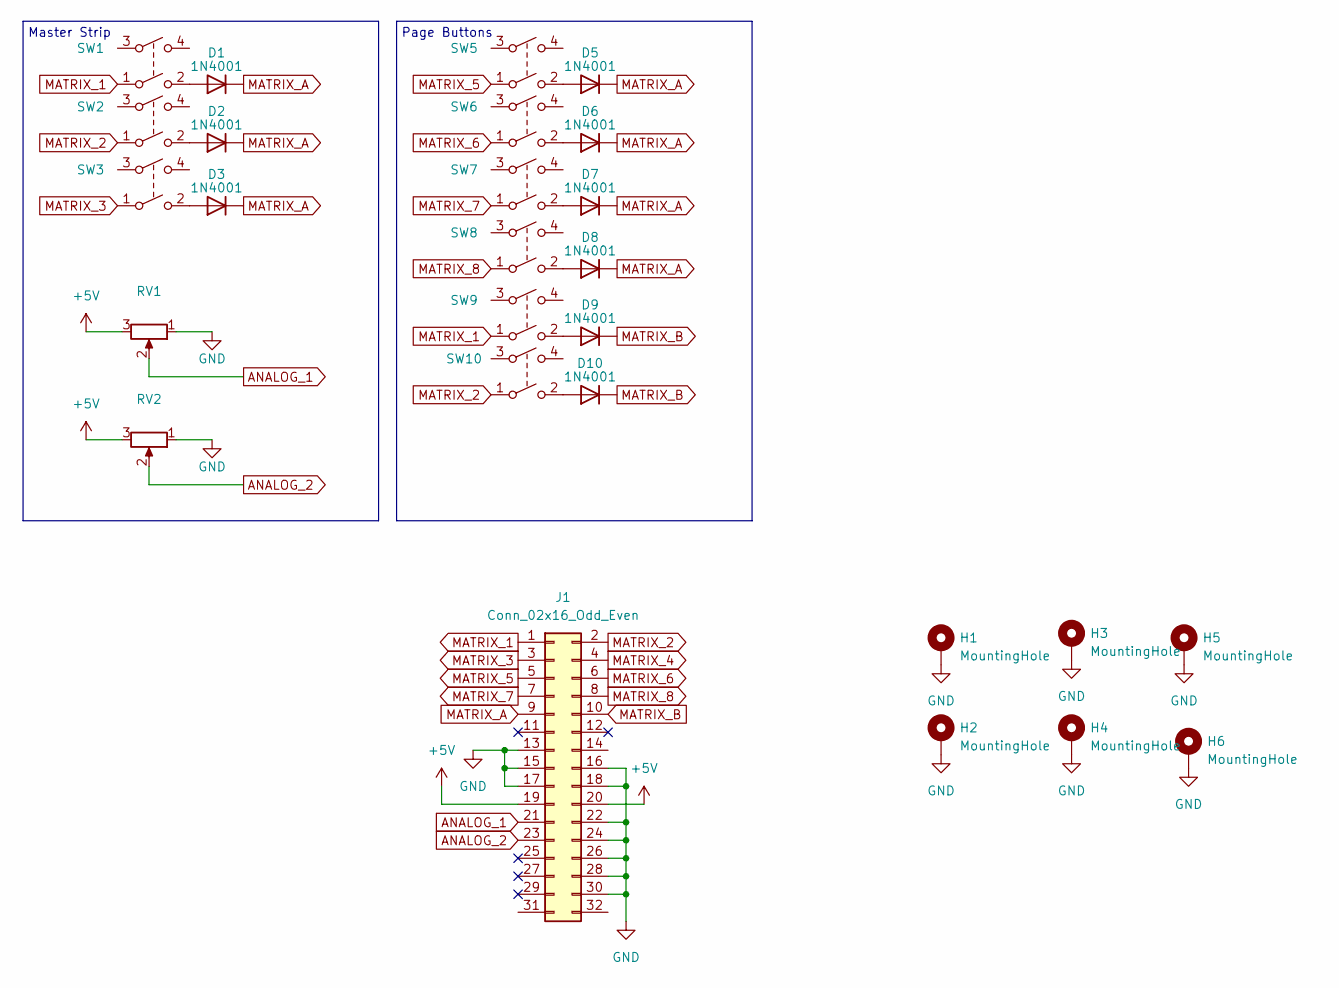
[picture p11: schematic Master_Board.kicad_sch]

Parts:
D1, D2, D3, D5, D6, D7, D8, D9, D10: 1N4001; D_DO-41_SOD81_P10.16mm_Horizontal
H1, H2, H3, H4, H5, H6: MountingHole; MountingHole_3.2mm_M3_DIN965_Pad
J1: Conn_02x16_Odd_Even; IDC-Header_2x15_P2.54mm_Latch6.5mm_Vertical
RV1, RV2: (no value)
SW1, SW2, SW3: (no value)
SW5, SW6, SW7, SW8, SW9, SW10: Switch_SW_DPST; SW_Cherry_MX_PCB_1.00u

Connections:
+5V: J1.19, J1.20, RV1.3, RV2.3
ANALOG_1: J1.21, RV1.2
ANALOG_2: J1.23, RV2.2
GND: H1.1, H2.1, H3.1, H4.1, H5.1, H6.1, J1.13, J1.15, J1.16, J1.17, J1.18, J1.22, J1.24, J1.26, J1.28, J1.30, RV1.1, RV2.1
MATRIX_1: J1.1, SW1.1, SW9.1
MATRIX_2: J1.2, SW2.1, SW10.1
MATRIX_3: J1.3, SW3.1
MATRIX_4: J1.4
MATRIX_5: J1.5, SW5.1
MATRIX_6: J1.6, SW6.1
MATRIX_7: J1.7, SW7.1
MATRIX_8: J1.8, SW8.1
MATRIX_A: D1.1 (K), D2.1 (K), D3.1 (K), D5.1 (K), D6.1 (K), D7.1 (K), D8.1 (K), J1.9
MATRIX_B: D9.1 (K), D10.1 (K), J1.10
unnamed: D1.2 (A), SW1.2
unnamed: D2.2 (A), SW2.2
unnamed: D3.2 (A), SW3.2
unnamed: D5.2 (A), SW5.2
unnamed: D6.2 (A), SW6.2
unnamed: D7.2 (A), SW7.2
unnamed: D8.2 (A), SW8.2
unnamed: D9.2 (A), SW9.2
unnamed: D10.2 (A), SW10.2

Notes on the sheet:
Page Buttons
Master Strip

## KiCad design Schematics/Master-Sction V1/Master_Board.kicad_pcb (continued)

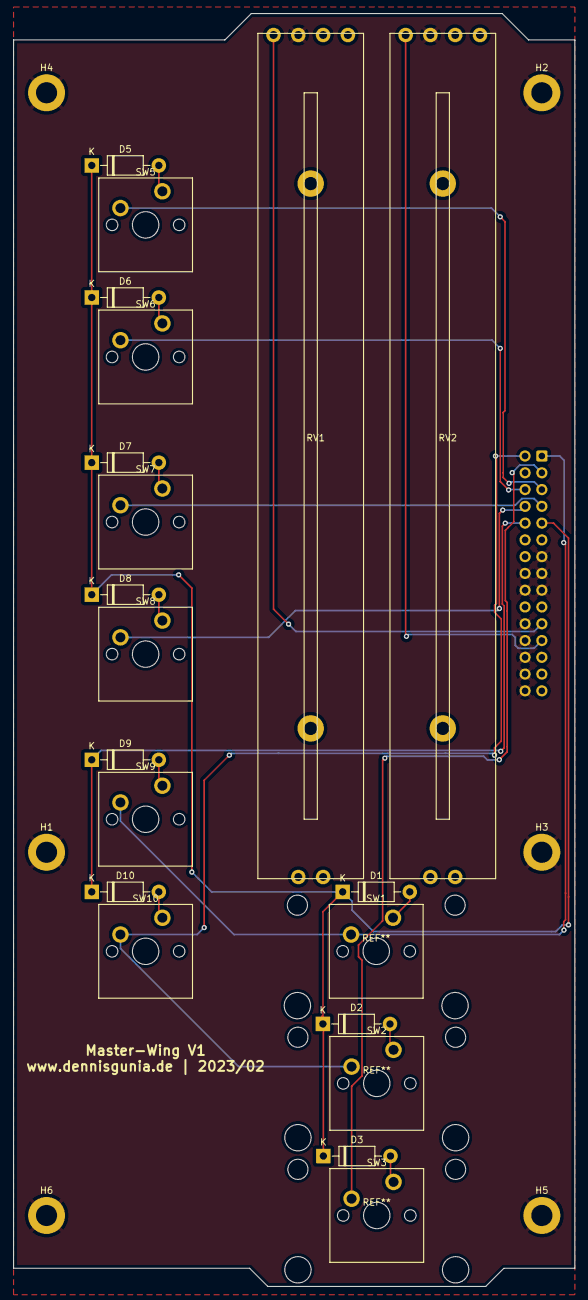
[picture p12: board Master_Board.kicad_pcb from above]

Board: 2 copper layers, 85.0 x 192.8 mm, 27 parts (1 on the bottom side), 22 nets.

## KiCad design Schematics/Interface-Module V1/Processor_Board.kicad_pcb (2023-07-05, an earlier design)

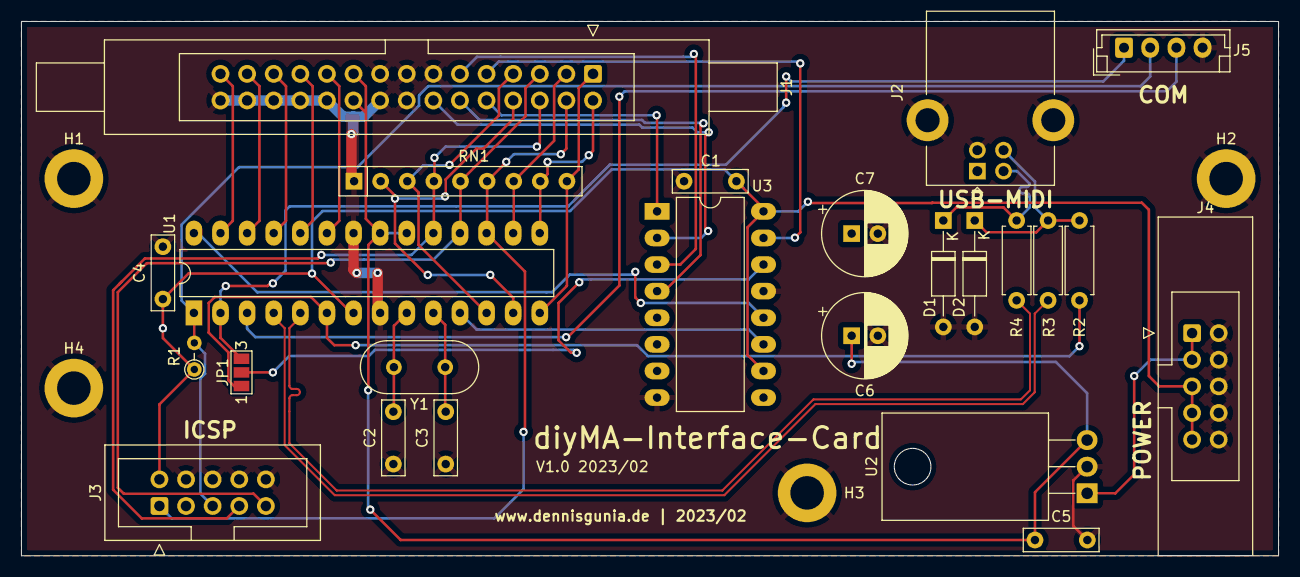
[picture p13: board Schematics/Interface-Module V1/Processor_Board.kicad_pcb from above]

Board: 2 copper layers, 120.0 x 51.0 mm, 28 parts (0 on the bottom side), 35 nets.

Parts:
C1, C4, C5: 100nF; C_Rect_L7.0mm_W2.0mm_P5.00mm
C2, C3: 33pF; C_Rect_L7.0mm_W2.0mm_P5.00mm
C6, C7: 100uF; CP_Radial_D8.0mm_P2.50mm
D1, D2: 3V6; D_DO-35_SOD27_P10.16mm_Horizontal
H1, H2, H3, H4: MountingHole; MountingHole_3.2mm_M3_DIN965_Pad
J1: Conn_02x16_Odd_Even; IDC-Header_2x15_P2.54mm_Latch6.5mm_Vertical
J2: USB_B; USB_B_Lumberg_2411_02_Horizontal
J3: Conn_02x05_Odd_Even; IDC-Header_2x05_P2.54mm_Vertical
J4: Conn_02x05_Odd_Even; IDC-Header_2x05_P2.54mm_Latch_Vertical
J5: Conn_01x04_Male; JST_EH_B4B-EH-A_1x04_P2.50mm_Vertical
JP1: Jumper_3_Open; SolderJumper-3_P1.3mm_Open_Pad1.0x1.5mm_NumberLabels
R1: 10k; R_Axial_DIN0204_L3.6mm_D1.6mm_P2.54mm_Vertical
R2: 2k2; R_Axial_DIN0207_L6.3mm_D2.5mm_P7.62mm_Horizontal
R3, R4: 68; R_Axial_DIN0207_L6.3mm_D2.5mm_P7.62mm_Horizontal
RN1: R_Network08; R_Array_SIP9
U1: ATmega8-16P; DIP-28_W7.62mm_LongPads
U2: L7805; TO-220-3_Horizontal_TabDown
U3: 74HC595; DIP-16_W10.16mm_LongPads
Y1: 16MHz; Crystal_HC18-U_Vertical

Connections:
+5V: C1.1, C4.1, C7.1, J3.2, J4.5, J4.7, J4.9, R1.1, U1.7 (VCC), U3.10 (~SRCLR), U3.16 (VCC)
+5VA: C5.1, C6.1, J1.19, J1.20, U1.20 (AVCC), U1.21 (AREF), U2.3 (OUT)
+12V: J4.1, J4.3, U2.1 (IN)
/#USB_D+: D2.1 (K), J2.3 (D+), R2.1, R3.1
/#USB_D-: D1.1 (K), J2.2 (D-), R4.1
ANALOG_1: J1.21, U1.23 (PC0)
ANALOG_2: J1.23, U1.24 (PC1)
ANALOG_3: J1.25, U1.25 (PC2)
ANALOG_4: J1.27, U1.26 (PC3)
ANALOG_5: J1.29, U1.27 (PC4)
GND: C1.2, C2.1, C3.1, C4.2, C5.2, C6.2, C7.2, D1.2 (A), D2.2 (A), H1.1, H2.1, H3.1, H4.1, J1.13, J1.15, J1.16, J1.17, J1.18, J1.22, J1.24, J1.26, J1.28, J1.30, J2.4 (GND), J2.5 (Shield), J3.4, J3.6, J3.8, J3.10, J4.2, J4.4, J4.6, J4.8, J4.10, J5.4, RN1.1 (common), U1.8 (GND), U1.22 (AGND), U2.2 (GND), U3.8 (GND), U3.13 (~OE)
ICSP_MISO: J1.5, J3.9, RN1.5 (R4), U1.18 (PB4)
ICSP_MOSI: J1.4, J3.1, RN1.6 (R5), U1.17 (PB3)
ICSP_SCK: J1.6, J3.7, RN1.4 (R3), U1.19 (PB5)
MATRIX_1: J1.1, RN1.9 (R8), U1.14 (PB0)
MATRIX_2: J1.2, RN1.8 (R7), U1.15 (PB1)
MATRIX_3: J1.3, RN1.7 (R6), U1.16 (PB2)
MATRIX_7: J1.7, RN1.3 (R2), U1.12 (PD6)
MATRIX_8: J1.8, RN1.2 (R1), U1.13 (PD7)
MATRIX_A: J1.9, U3.15 (QA)
MATRIX_B: J1.10, U3.1 (QB)
MATRIX_C: J1.14, U3.2 (QC)
MATRIX_D: J1.11, U3.3 (QD)
MATRIX_E: J1.12, U3.4 (QE)
unnamed: C2.2, U1.9 (PB6/XTAL1), Y1.2
unnamed: C3.2, U1.10 (PB7/XTAL2), Y1.1
unnamed: JP1.2 (C), U3.14 (SER)
unnamed: U1.11 (PD5), U3.11 (SRCLK)
unnamed: U1.28 (PC5), U3.12 (RCLK)
RS232_RX/SER: J5.1, JP1.3 (B), U1.2 (PD0)
RS232_TX: J5.3, U1.3 (PD1)
USB_D+: R3.2, U1.4 (PD2)
USB_D-: R4.2, U1.5 (PD3)
USB_INT/SER: JP1.1 (A), R2.2, U1.6 (PD4)
~RESET: J3.5, J5.2, R1.2, U1.1 (PC6/~RESET)

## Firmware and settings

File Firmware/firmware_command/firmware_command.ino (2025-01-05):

#include <Arduino.h>


#define FADER1 A0

#define SR_DATA A5  //19
#define SR_CLOCK 5
#define SR_LATCH A4  //18
#define MTX_I 2      //18

bool last_button_state[80];


/* 
  UART-Init: 
Berechnung des Wertes für das Baudratenregister 
aus Taktrate und gewünschter Baudrate
*/

#ifndef F_CPU
#define F_CPU 16000000UL  
#endif

/// CONFIG
#define BAUD 19200UL  // Baudrate
#define CHANNEL 4     // midi channel
#define OFFSET 0      // first midi note

// Berechnungen
#define UBRR_VAL ((F_CPU + BAUD * 8) / (BAUD * 16) - 1)  // clever runden
#define BAUD_REAL (F_CPU / (16 * (UBRR_VAL + 1)))        // Reale Baudrate
#define BAUD_ERROR ((BAUD_REAL * 1000) / BAUD)           // Fehler in Promille, 1000 = kein Fehler.

#if ((BAUD_ERROR < 990) || (BAUD_ERROR > 1010))
#error Systematischer Fehler der Baudrate grösser 1% und damit zu hoch!
#endif

void setup() {
  // prints title with ending line break
  for (int i = 0; i < 80; i++) {
    last_button_state[i] = 0;
  }

  //DDRB |= 0b00111111;  // PORT_A contains matrix rows 1-2
  //DDRD |= 0b11000000;  // PORT_B contains matrix rows 3-8

  pinMode(SR_DATA, OUTPUT);
  pinMode(SR_CLOCK, OUTPUT);
  pinMode(SR_LATCH, OUTPUT);
  pinMode(MTX_I, OUTPUT);

  //pinMode(12, OUTPUT);  // 1
  //pinMode(11, OUTPUT);  // 2
  //pinMode(2, OUTPUT);   // 3
  //pinMode(3, OUTPUT);   // 4
  //pinMode(4, OUTPUT);   // 5
  //pinMode(5, OUTPUT);   // 6
  //pinMode(6, OUTPUT);   // 7
  //pinMode(7, OUTPUT);   // 8
  //pinMode(8, INPUT);    // A
  //pinMode(9, INPUT);    // B
  //pinMode(10, INPUT);   // V

  // init uart
  UBRR0 = UBRR_VAL;
  UCSR0B |= (1 << TXEN0);
  UCSR0B |= (1 << RXEN0);
  // Frame Format: Asynchron 8N1
  UCSR0C = (1 << UCSZ01) | (1 << UCSZ00);
  UCSR0B |= (1 << RXCIE0);
  sei();
}


int uart_putc(unsigned char c) {
  while (!(UCSR0A & (1 << UDRE0))) /* warten bis Senden moeglich */
  {
  }

  UDR0 = c; /* sende Zeichen */
  return 0;
}

// first visible ASCIIcharacter '!' is number 33:
int thisByte = 33;
// you can also write ASCII characters in single quotes.
// for example, '!' is the same as 33, so you could also use this:
// int thisByte = '!';

uint8_t noteON = B10010000;
uint8_t noteOFF = B10000000;

int last_fader[1] = { 0 };
int pins_fader[1] = { FADER1 };

char buttons[3] = { 'A', 'B', 'C' };
char in_msg[63];  //ringbuffer for incomming midi

uint16_t in_index_last = 0;
uint16_t in_index_top = 0;

long int lastin = 0;
int in_last = 0;

void loop() {
  processAnalog();
  //processQueue();
  processMatrix();
  //processQueue();
}

uint8_t start_ch = OFFSET;

void midi_put_buffer(char data) {
  //clear buffer if last tx is 1 sec ago
  long int now = millis();
  if (now - lastin > 1000) {
    in_index_top = 0;
    in_index_last = 0;
  }
  lastin = now;

  in_msg[in_index_top] = data;
  in_index_top++;
  if (in_index_top >= 63) {
    in_index_top = 0;
  }
}


void midi_send_buffer_single() {
  uint16_t diff = 0;
  if (in_index_top < in_index_last) {
    diff = (63 + in_index_top) - in_index_last;
  } else {
    diff = in_index_top - in_index_last;
  }
  if (diff > 2) {
    uart_putc(in_msg[in_index_last + 0]);
    uart_putc(in_msg[in_index_last + 1]);
    uart_putc(in_msg[in_index_last + 2]);
    in_index_last += 3;
    if (in_index_last >= 63) {
      in_index_last -= 63;
    }
  }
}


ISR(USART_RX_vect) {
  unsigned char b;
  b = UDR0;
  midi_put_buffer(b);
}

void processQueue() {
  midi_send_buffer_single();
}

void processAnalog() {
  for (int i = 0; i < 1; i++) {
    int val = analogRead(pins_fader[i]);
    if (val - last_fader[i] > 2 || val - last_fader[i] < -2) {
      sendMessageNote(CHANNEL, 1 + i, map(val, 1, 1022, 127, 0));
      last_fader[i] = val;
    } else if ((val < 2 && last_fader[i] > 2) || (val > 1022 && last_fader[i] < 1022)) {
      sendMessageNote(CHANNEL, 1 + i, map(val, 1, 1022, 127, 0));
      last_fader[i] = val;
    }
  }
}

void srClock(uint8_t bit) {
  digitalWrite(SR_DATA, bit);
  digitalWrite(SR_CLOCK, 1);
  digitalWrite(SR_CLOCK, 0);
  digitalWrite(SR_LATCH, 1);
  digitalWrite(SR_LATCH, 0);
}

void processMatrix() {
  srClock(1);  //shift 1st byte
  for (int i = 0; i < 9; i++) {
    if (i == 8) {
      digitalWrite(MTX_I, HIGH);
    } else {
      digitalWrite(MTX_I, LOW);
    }

    int baseId = i * 8;
    uint8_t data = getMatrix();

    for (int b = 0; b < 8; b++) {
      bool state = ((data & _BV(b)) > 0);
      if (state != last_button_state[baseId + b]) {
        last_button_state[baseId + b] = state;
        sendMessageNote(CHANNEL, 2 + baseId + b, state ? 127 : 0);
      }
    }

    //shift 0 byte
    srClock(0);
  }
}

uint8_t getMatrix() {
  uint8_t val1 = PINB & 0b00111111;
  uint8_t val2 = PIND & 0b11000000;
  return (val1 | val2);
}

void sendMessageNote(uint8_t channel, uint8_t note, int velocity) {
  uint8_t statusByte = (velocity > 0 ? noteON : noteOFF) & 0xF0;
  statusByte |= channel & 0x0F;

  uart_putc(statusByte);
  uart_putc(start_ch + note);
  uart_putc(velocity);
}

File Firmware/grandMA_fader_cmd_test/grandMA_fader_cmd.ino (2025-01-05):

/*
  Analog input, analog output, serial output

  Reads an analog input pin, maps the result to a range from 0 to 255 and uses
  the result to set the pulse width modulation (PWM) of an output pin.
  Also prints the results to the Serial Monitor.

  The circuit:
  - potentiometer connected to analog pin 0.
    Center pin of the potentiometer goes to the analog pin.
    side pins of the potentiometer go to +5V and ground
  - LED connected from digital pin 9 to ground through 220 ohm resistor

  created 29 Dec. 2008
  modified 9 Apr 2012
  by Tom Igoe

  This example code is in the public domain.

  https://www.arduino.cc/en/Tutorial/BuiltInExamples/AnalogInOutSerial
*/

// These constants won't change. They're used to give names to the pins used:
const int analogInPin = A0;  // Analog input pin that the potentiometer is attached to
const int analogOutPin = 9; // Analog output pin that the LED is attached to

int sensorValue = 0;        // value read from the pot
int outputValue = 0;        // value output to the PWM (analog out)

void setup() {
  // initialize serial communications at 9600 bps:
  Serial.begin(9600);
}

void loop() {
  // print the results to the Serial Monitor:
  Serial.print(readOne(A0));
  Serial.print(",");
  Serial.print(readOne(A1));
  Serial.print(",");
  Serial.print(readOne(A2));
  Serial.print(",");
  Serial.print(readOne(A3));
  Serial.print(",");
  Serial.println(readOne(A4));

  // wait 2 milliseconds before the next loop for the analog-to-digital
  // converter to settle after the last reading:
  delay(2);
}

int readOne(int inputPin){
  sensorValue = constrain(analogRead(inputPin),5,1020);
  outputValue = map(sensorValue, 5, 1020, 127,0);
  return outputValue;
}
